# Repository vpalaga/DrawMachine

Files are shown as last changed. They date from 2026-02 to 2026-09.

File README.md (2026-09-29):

# Draw Machine by VPalaga 

The idea is to make a plotter.

 The FCODE is my own simplification of .gcode protocol. I maight implememnt the .gcode later for the sake of my own sanity, but for now I am working with my own fuck creation - FCODE.

**The Goal: 100% working reliable x, y potter to do my homework.** 

>Partially based on Scrabble bot.
---

## .FCODE (quite old examples, they are not accurate at all <3)
>**FCODE Generation example in `FCODEgenerator/useExample.py`**  

``` python
from FCODEgenerator.main import FGenerator

# create a generatin object
gen = FGenerator("train_v1.dxf", acc=.1, vis_scale=10, text=False)

# generate the FCODE from the provided dxf file
gen.generate_instructions()
 # the save format / location can be configured under gen.py method: save()
gen.save()
```

Payload from Pi to Pico examples (FCODE):
```
CALIBRATE
MOVE 45.478 3.671
PENUP
MOVE 67.092 89.082
PENDOWN 
```
| Function | Arguments | Description |
| --- | --- | --- |
| MOVE | 2 | move the head to the x, y position| 
| WAIT | 1 |wait *x* seconds |
| CALIBRATE | 0 | calibrate the head (using the swiches at 0, 0) |
| *PENUP* | 0 | set the pen positon to be up |
| *PENDOWN* | 0 | set the pen position to be down| 

> Current functions: (can be found under `FCODEgenerator.segmentFunctions.Instruction.instructions_parameters_len.keys()`

---
## Raspberry Pi
*Python on Raspberry Pi 4B*   
+ file reading
+ run `MotorControl`
+ send float x, y coordinates to Raspberry Pico 2W
+ control servo on the head (*depending on the current use*) or head in general (PCA PCB)
+ > maybe even web server host for FCODE upload or remote stearing 

> To implement multifunctions, the Inscructions need to have be adjusted to the new argument length 
---
## Raspberry Pico  
Microcontroller running the main `c` loop, basicaly the PICO is just a dual simultanious stepper driver: 
+ recive functions
+ respond with error/confirmantion messages (CDC)
+ drive the end swiches (draw current when closed)
+ Send logic to x, y TMC 2209 Drivers

I am using **Raspberry Pi Pico VS Code extension** to write, compile and upload the code to my Pico.

---
### The idea for the c++ code running on the pico:
USB CDC Virtual Serial data exchange, to send `MOVE` coordinates to the pico.

> CDC Example
``` cpp
// Pico: client
while (true) {
        if (stdio_usb_connected(w)) {
            // read a char if available
            int c = getchar_timeout_us(0);

            if (c >= 0) {
                printf("Got char: %c\n", (char)c);
            }
        }
        sleep_ms(10);
    }
```
> install Python lib `pyserial`
``` python
import serial
import time

# replace with your Pico’s serial port name;
# on Linux it might be "/dev/ttyACM0" or similar
# on Windows something like "COM3"
SERIAL_PORT = "COM14"
BAUDRATE = 115200

# open the serial connection
ser = serial.Serial(SERIAL_PORT, BAUDRATE, timeout=1)

time.sleep(2)    # short delay to let the port settle
ser.write(b"hello world!") # make shure you send the tring in byte type
    
# send a line to the Pico
try:
    while True:

        line_raw = ser.readline()
        line = line_raw.decode().strip()
        if line != "Got char:" and line != "":
            print(line)
        time.sleep(.01)
finally:
    ser.close()
    exit()
```
### Stepping

Stepps moves are computed by Bresenham move function

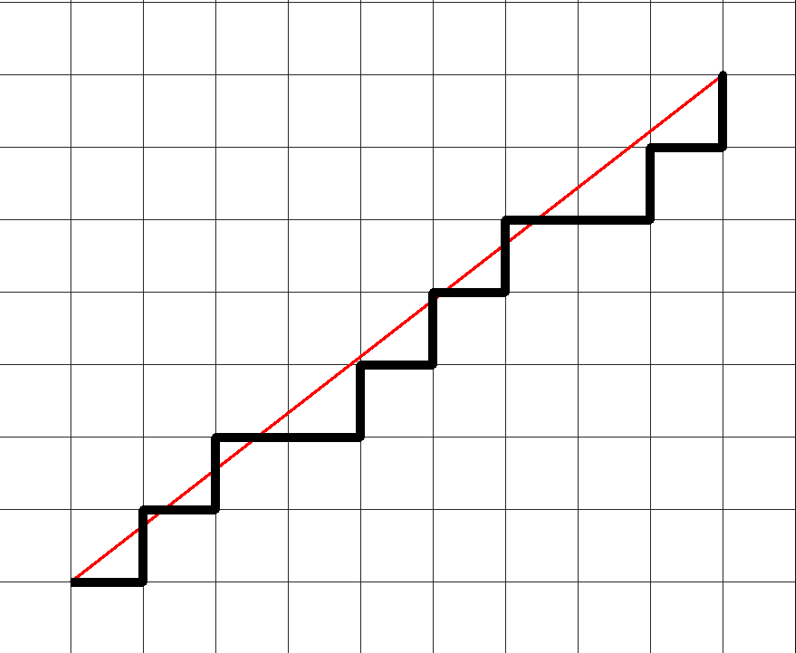
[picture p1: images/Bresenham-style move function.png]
./images/Bresenham-style move function.png


```cpp
class StepperDriver{
public:
    Stepper xStepperMotor;
    Stepper yStepperMotor;

    StepperDriver()
        : xStepperMotor(X_STP_STEPPER_PIN, X_DIR_STEPPER_PIN, 100),
          yStepperMotor(Y_STP_STEPPER_PIN, Y_DIR_STEPPER_PIN, 100) {
    }
    void bresenham(Stepper leadStepper, Stepper followStepper, int lead, int follow, bool leadDir, bool followDir){
        // how many steps of follow pro one step of lead
        float bresenhamStep = (float)follow / lead; // needs to be <0 

        int followPos   = 0;
        int followCycle;
        int diffFollowCycle;

        for (int cycle = 1; cycle<lead+1; cycle++){ // cycle need to start at 1
            
            // calculate how many steps at current cycle position 
            followCycle = round(cycle*bresenhamStep);
            
            // check how many are needed for this cycle
            diffFollowCycle = followCycle - followPos;

            // update the followPos to current follow position
            followPos += diffFollowCycle;

            //move the steppers accordingly
            // step: bool: dir, int steps, microseconds_sleep
            leadStepper.step(leadDir,1,100);
            followStepper.step(followDir,diffFollowCycle,100); // move the follow if needed
        }
    }

    void move(int x, int y){

        bool x_dir = (x<0) ? false : true; // change if the direction is wrong
        bool y_dir = (y<0) ? false : true;

        // set both to positive
        x = abs(x); y = abs(y);

        if (x >= y){ // x = lead
            bresenham(xStepperMotor, yStepperMotor, x, y, x_dir, y_dir);    
        } else { // y = lead
            bresenham(yStepperMotor, xStepperMotor, y, x, y_dir, x_dir);
        }
    }

};

```

---

# Construction
fuck you, find your own parts. I dont care about the nobody reading this to spend my time on this :D
# Code Documentation

Good luck figuring it out on your own. I have no idea either.

## Libraries used:
I have no clue. 
Just go check it lol.

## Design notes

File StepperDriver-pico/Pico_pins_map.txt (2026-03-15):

                              _______
                        ______|     |______
                    GP0 | 1             40|VBUS
                    GP1 | 2  GP25|LED   39|VSYS
                    GND | 3             38| GND      
Swich control X+    GP2 | 4             37|3v3e     
Swich control Y+    GP3 | 5             36|3V3O     3V3 Source
Swich control X-    GP4 | 6             35|
Swich control Y-    GP5 | 7             34|GP28     LED instruction
                    GND | 8             33| GND     Swich DRAIN
Swich B1            GP6 | 9             32|GP27     Swich X pull
Swich B2            GP7 |10             31|GP26     Swich Y pull
PCA9685 I2C_SDA     GP8 |11             30|RUN
PCA9685 I2C_SCL     GP9 |12             29|GP22
PCA9685 GND         GND |13             28| GND     TMC enable
                    GP10|14             27|GP21     TMC Y step
                    GP11|15             26|GP20     TMC Y dir
                    GP12|16             25|GP19     TMC X step
                    GP13|17             24|GP18     TMC X dir
                    GND |18             23| GND     TMC GND
HW069 display CLK   GP14|19             22|GP17     LED consolemode (blue)
HW069 display DIO   GP15|20             21|GP16     LED 2 (no use now)

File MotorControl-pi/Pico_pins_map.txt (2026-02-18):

                              _______
                        ______|     |______
                    GP0 | 1             40|VBUS
                    GP1 | 2             39|VSYS
                    GND | 3             38| GND      
                    GP2 | 4             37|3v3e     
                    GP3 | 5             36|3V3O     3V3 Source
                    GP4 | 6             35|
                    GP5 | 7             34|GP28
                    GND | 8             33| GND     Swich DRAIN
                    GP6 | 9             32|GP27     Swich Y pull
                    GP7 |10             31|GP26     Swich X pull
PCA9685 I2C_SDA     GP8 |11             30|RUN
PCA9685 I2C_SCL     GP9 |12             29|GP22
PCA9685 GND         GND |13             28| GND     TMC enable
Swich control X+    GP10|14             27|GP21     TMC X step
Swich control X-    GP11|15             26|GP20     TMC X dir
Swich control Y+    GP12|16             25|GP19     TMC Y step
Swich control Y-    GP13|17             24|GP18     TMC Y dir
Swich, HW069 GND    GND |18             23| GND     TMC GND
HW069 display CLK   GP14|19             22|GP17     LED instruction
HW069 display DIO   GP15|20             21|GP16     LED 2 (no use now)

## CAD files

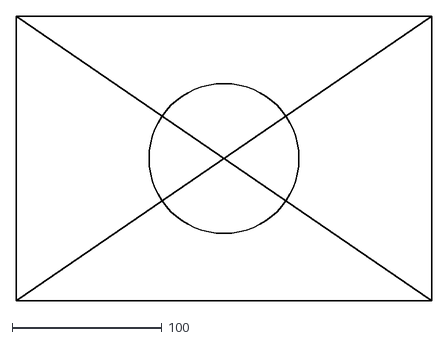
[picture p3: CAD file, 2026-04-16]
FCODEgenerator/dxfexamples/better_circle.dxf
277.0 x 190.0

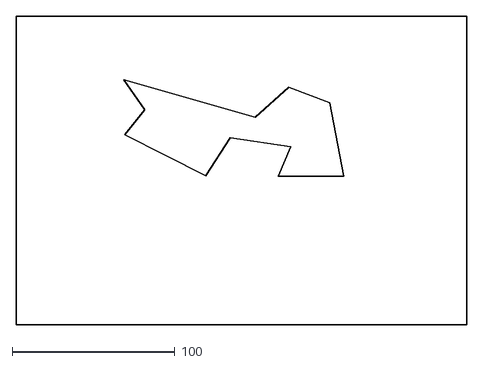
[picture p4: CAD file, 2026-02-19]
FCODEgenerator/simpleShape.dxf
277.0 x 190.0

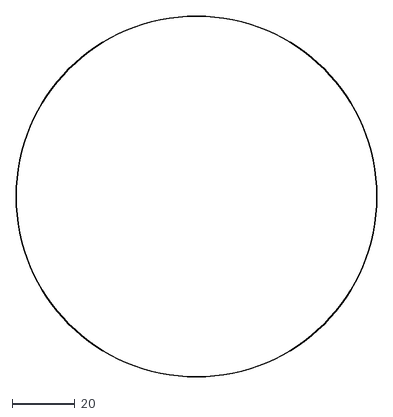
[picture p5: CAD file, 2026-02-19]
FCODEgenerator/dxfexamples/circle.dxf
114.5 x 114.5

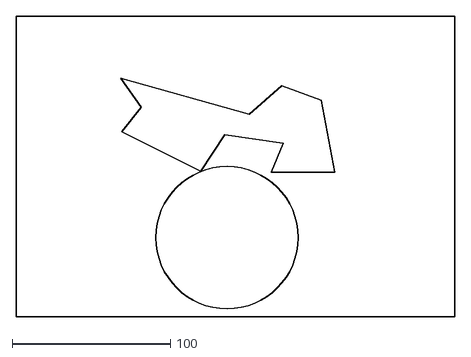
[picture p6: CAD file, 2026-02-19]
FCODEgenerator/dxfexamples/simpleShape(1).dxf
277.0 x 190.0

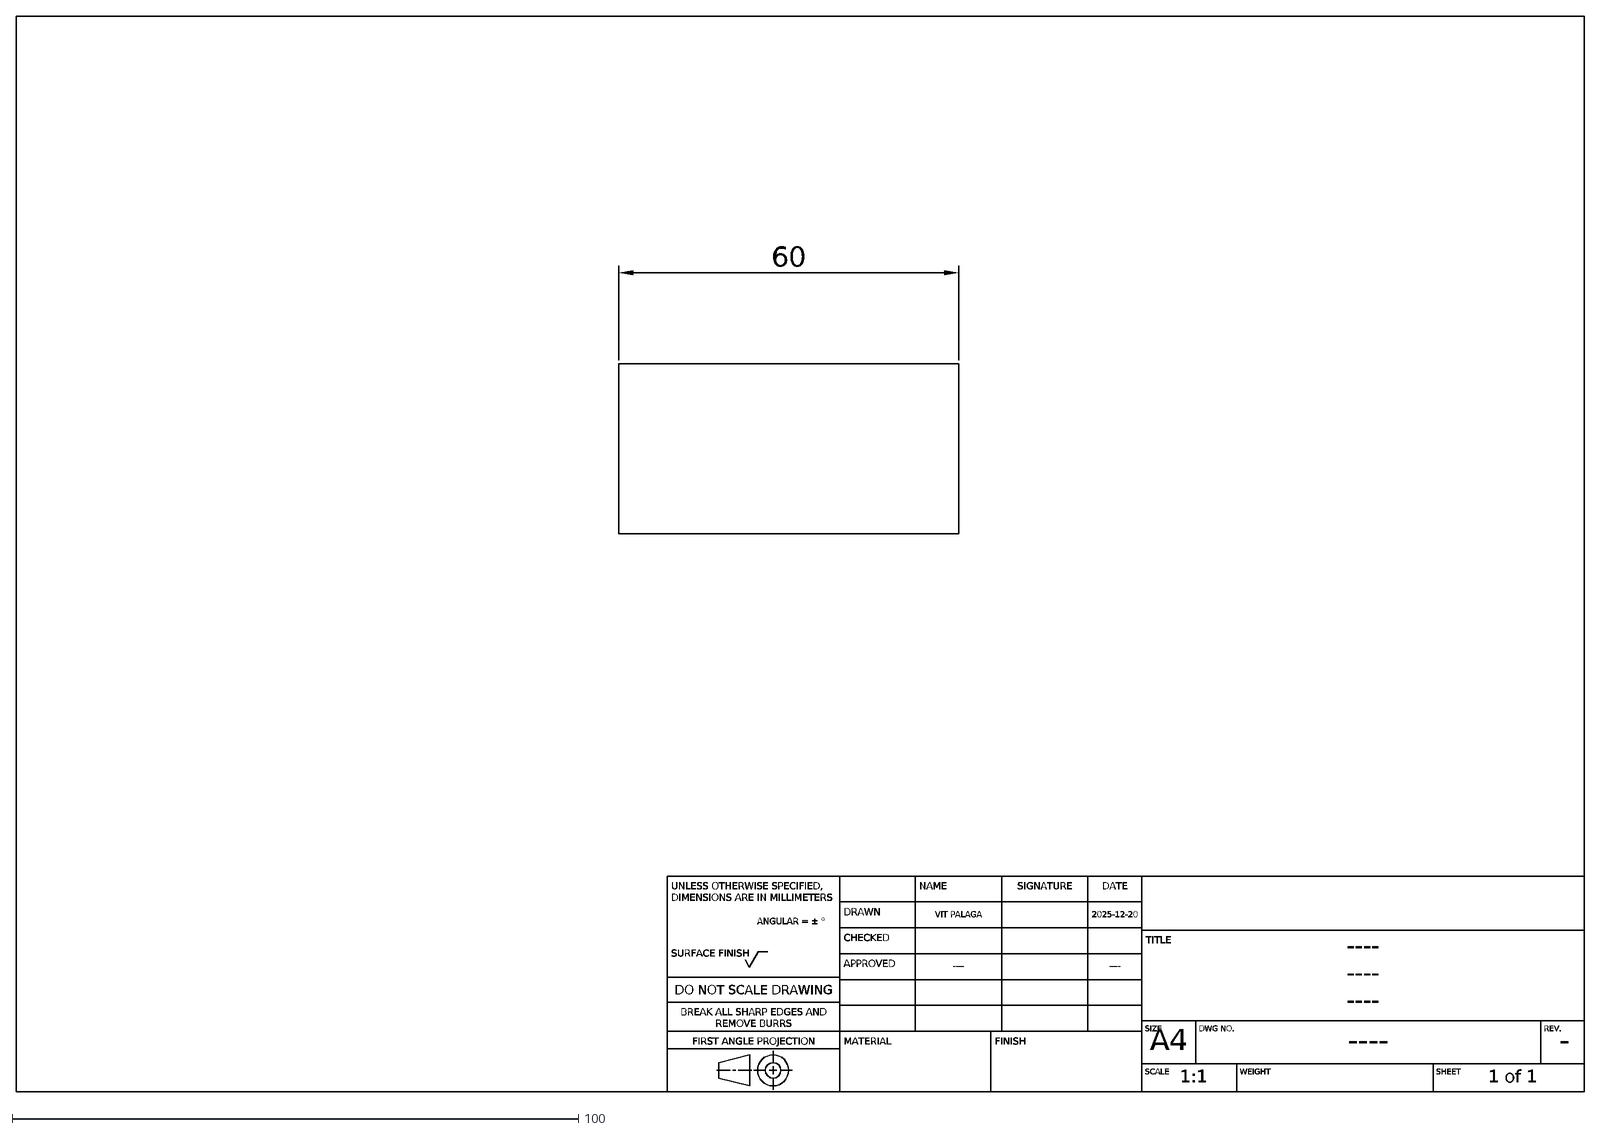
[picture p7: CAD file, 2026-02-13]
FCODEgenerator/dxfexamples/Drawing 2.dxf
UNLESS OTHERWISE SPECIFIED, DIMENSIONS ARE IN MILLIMETERS
ANGULAR = ± °
SURFACE FINISH
DO NOT SCALE DRAWING
BREAK ALL SHARP EDGES AND REMOVE BURRS
FIRST ANGLE PROJECTION
SIGNATURE
NAME
DATE
DRAWN
VIT PALAGA
2025-12-20
CHECKED
APPROVED
----
MATERIAL
FINISH
TITLE
SIZE
A4
DWG NO.
REV.
-
SCALE
1:1
WEIGHT
SHEET
1 of 1
60

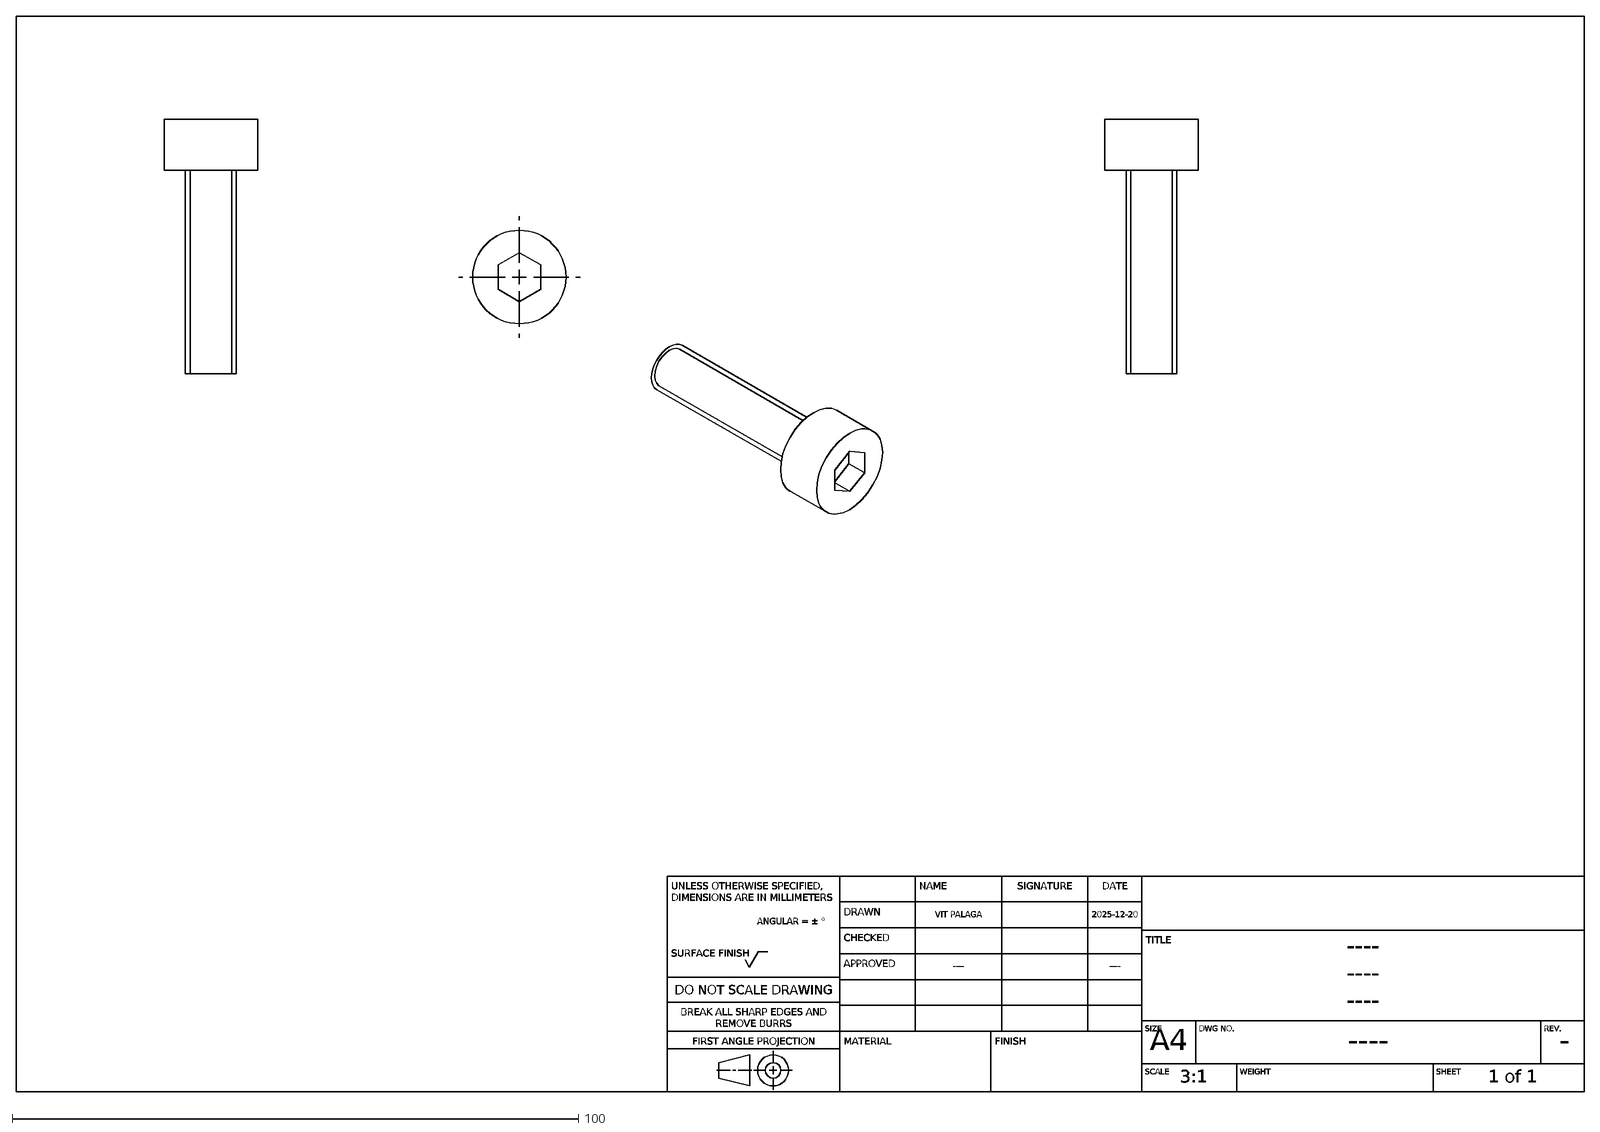
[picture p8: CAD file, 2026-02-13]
FCODEgenerator/dxfexamples/Drawing 1.dxf
UNLESS OTHERWISE SPECIFIED, DIMENSIONS ARE IN MILLIMETERS
ANGULAR = ± °
SURFACE FINISH
DO NOT SCALE DRAWING
BREAK ALL SHARP EDGES AND REMOVE BURRS
FIRST ANGLE PROJECTION
SIGNATURE
NAME
DATE
DRAWN
VIT PALAGA
2025-12-20
CHECKED
APPROVED
----
MATERIAL
FINISH
TITLE
SIZE
A4
DWG NO.
REV.
-
SCALE
3:1
WEIGHT
SHEET
1 of 1

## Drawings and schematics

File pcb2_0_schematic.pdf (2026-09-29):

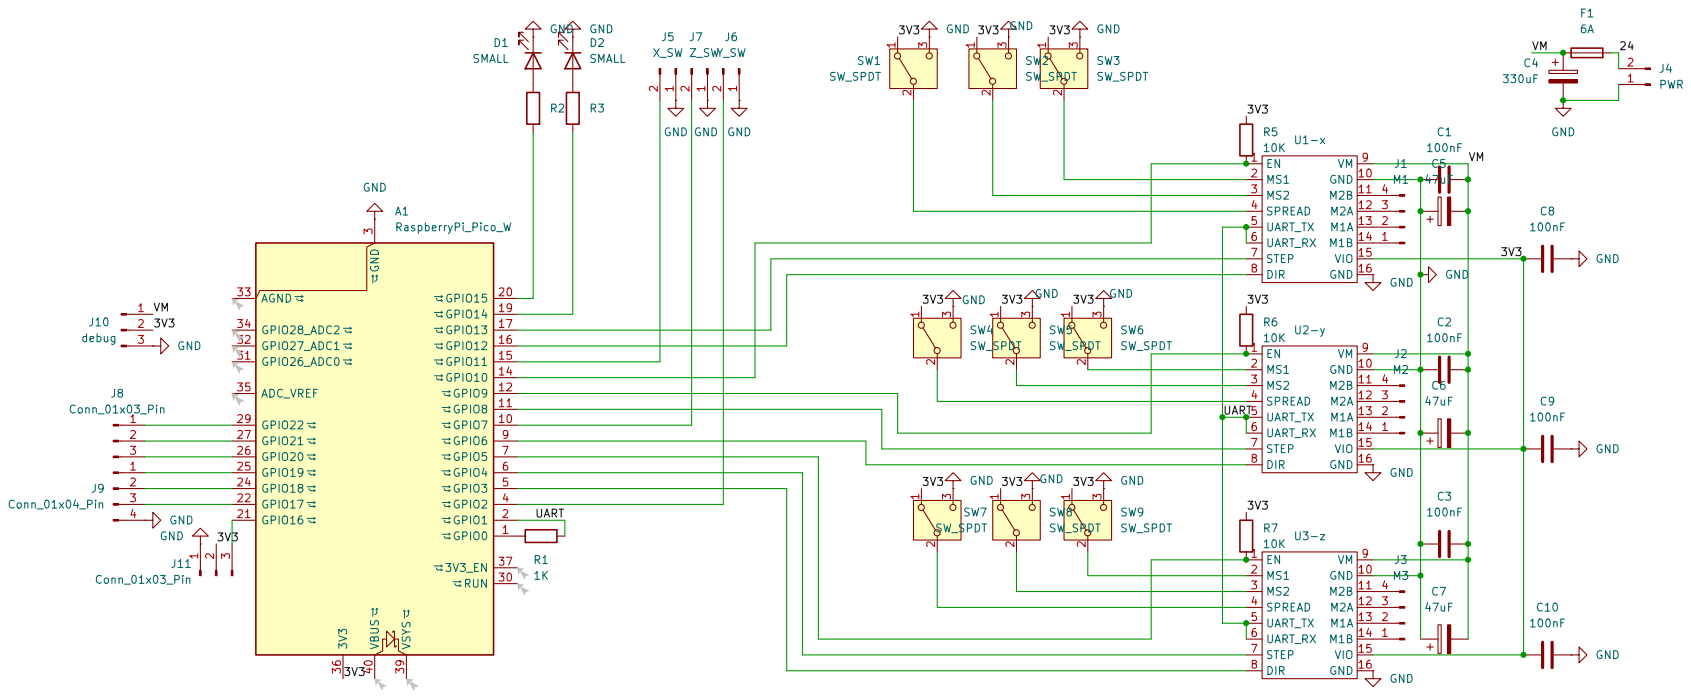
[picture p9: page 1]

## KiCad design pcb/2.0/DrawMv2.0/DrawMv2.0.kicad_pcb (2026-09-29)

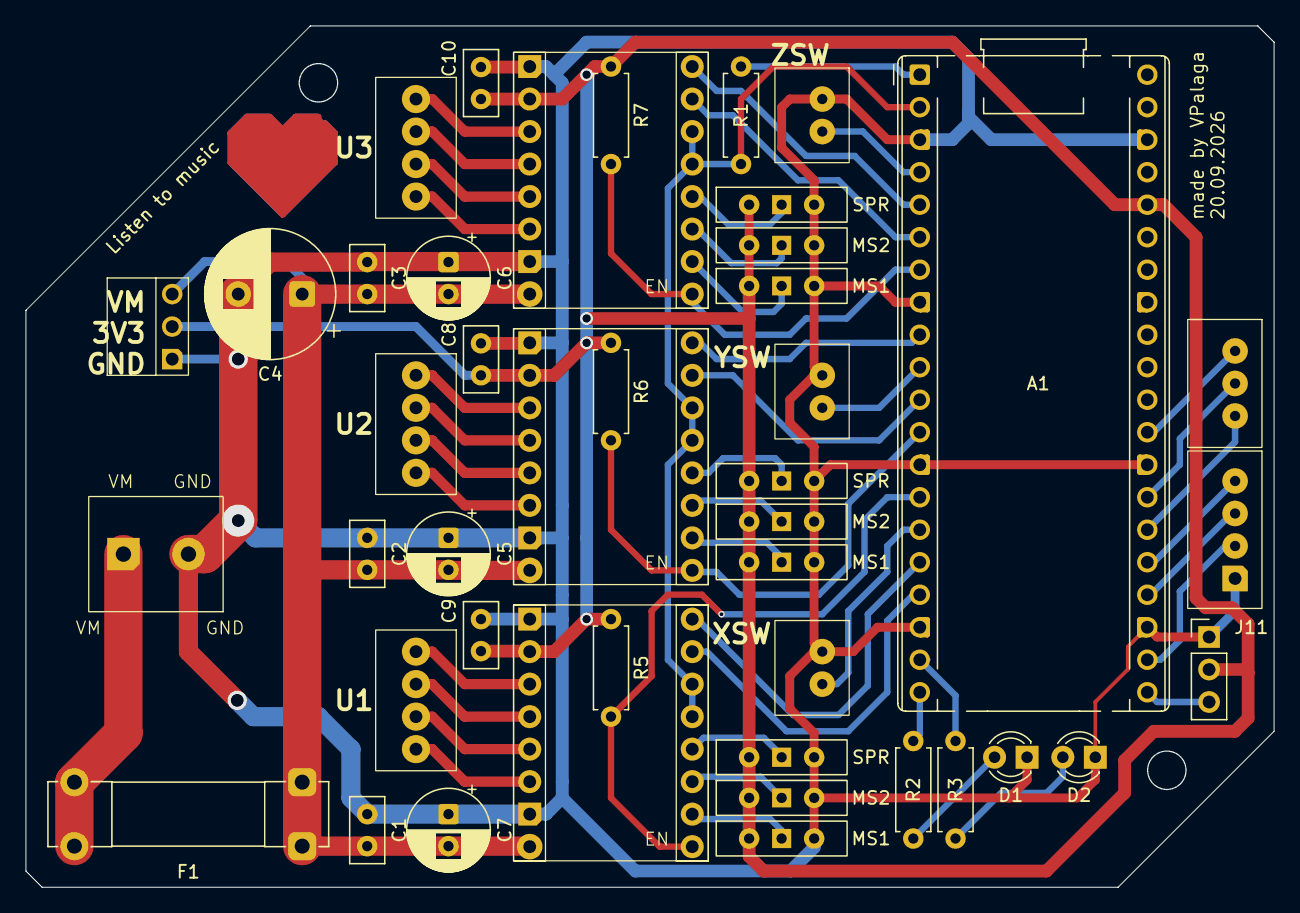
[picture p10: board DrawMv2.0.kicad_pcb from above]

Board: 2 copper layers, 97.5 x 67.3 mm, 43 parts (0 on the bottom side), 50 nets.

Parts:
A1: RaspberryPi_Pico_W; RaspberryPi_Pico_Common_THT
C1, C2, C3, C8, C9, C10: 100nF; C_Disc_D5.0mm_W2.5mm_P2.50mm
C4: 330uF; CP_Radial_D10.0mm_P5.00mm
C5, C6, C7: 47uF; CP_Radial_D6.3mm_P2.50mm
D1, D2: SMALL; LED_D3.0mm
F1: 6A; Fuseholder_Clip-5x20mm_Bel_FC-203-22_Lateral_P17.80x5.00mm_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
J1: M1; 4pinTerminal
J2: M2; 4pinTerminal
J3: M3; 4pinTerminal
J4: PWR; Untitled
J5: X_SW; XH2pin
J6: Y_SW; XH2pin
J7: Z_SW; XH2pin
J8: Conn_01x03_Pin; XH3pin
J9: Conn_01x04_Pin; XH4pin
J10: debug
J11: Conn_01x03_Pin; PinHeader_1x03_P2.54mm_Vertical
MS1, MS1#2, MS1#3, MS2, MS2#2, MS2#3: SW_SPDT; SW_Slide-03_Wuerth-WS-SLTV_10x2.5x6.4_P2.54mm_ok
R1: 1K; R_Axial_DIN0207_L6.3mm_D2.5mm_P7.62mm_Horizontal
R2, R3: R_Axial_DIN0207_L6.3mm_D2.5mm_P7.62mm_Horizontal
R5, R6, R7: 10K; R_Axial_DIN0207_L6.3mm_D2.5mm_P7.62mm_Horizontal
SPR: SW_SPDT; SW_Slide-03_Wuerth-WS-SLTV_10x2.5x6.4_P2.54mm_ok
SPR#2, SPR#3: SW_SPDT; SW_Slide-03_Wuerth-WS-SLTV_10x2.5x6.4_P2.54mm_ok
U1, U2, U3: TMC2209

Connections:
/3V3: A1.36 (3V3), C8.1, C9.1, C10.1, J10.2, J11.2, MS1.1 (A), MS1#2.1 (A), MS1#3.1 (A), MS2.1 (A), MS2#2.1 (A), MS2#3.1 (A), R5.1, R6.1, R7.1, SPR.1 (A), SPR#2.1 (A), SPR#3.1 (A), U1.15 (VIO), U2.15 (VIO), U3.15 (VIO)
/24: F1.2, J4.2
/UART: A1.2 (GPIO1), R1.1, U1.5 (UART_TX), U1.6 (UART_RX), U2.5 (UART_TX), U2.6 (UART_RX), U3.5 (UART_TX), U3.6 (UART_RX)
/VM: C1.2, C2.2, C3.2, C4.1, C5.2, C6.2, C7.2, F1.1, J10.1, U1.9 (VM), U2.9 (VM), U3.9 (VM)
GND: A1.3 (GND), A1.8 (GND), A1.13 (GND), A1.18 (GND), A1.23 (GND), A1.28 (GND), A1.38 (GND), C1.1, C2.1, C3.1, C4.2, C5.1, C6.1, C7.1, C8.2, C9.2, C10.2, D1.1 (K), D2.1 (K), J4.1, J5.1, J6.1, J7.1, J9.4, J10.3, J11.1, MS1.3 (C), MS1#2.3 (C), MS1#3.3 (C), MS2.3 (C), MS2#2.3 (C), MS2#3.3 (C), SPR.3 (C), SPR#2.3 (C), SPR#3.3 (C), U1.10 (GND), U1.16 (GND), U2.10 (GND), U2.16 (GND), U3.10 (GND), U3.16 (GND)
unnamed: A1.1 (GPIO0), R1.2
unnamed: A1.4 (GPIO2), J6.2
unnamed: A1.5 (GPIO3), U3.8 (DIR)
unnamed: A1.6 (GPIO4), U3.7 (STEP)
unnamed: A1.7 (GPIO5), R7.2, U3.1 (EN)
unnamed: A1.9 (GPIO6), U2.8 (DIR)
unnamed: A1.10 (GPIO7), J7.2
unnamed: A1.11 (GPIO8), U2.7 (STEP)
unnamed: A1.12 (GPIO9), R6.2, U2.1 (EN)
unnamed: A1.14 (GPIO10), R5.2, U1.1 (EN)
unnamed: A1.15 (GPIO11), J5.2
unnamed: A1.16 (GPIO12), U1.8 (DIR)
unnamed: A1.17 (GPIO13), U1.7 (STEP)
unnamed: A1.19 (GPIO14), R3.1
unnamed: A1.20 (GPIO15), R2.1
unnamed: A1.21 (GPIO16), J11.3
unnamed: A1.22 (GPIO17), J9.3
unnamed: A1.24 (GPIO18), J9.2
unnamed: A1.25 (GPIO19), J9.1
unnamed: A1.26 (GPIO20), J8.3
unnamed: A1.27 (GPIO21), J8.2
unnamed: A1.29 (GPIO22), J8.1
unnamed: D1.2 (A), R2.2
unnamed: D2.2 (A), R3.2
unnamed: J1.1, U1.14 (M1B)
unnamed: J1.2, U1.13 (M1A)
unnamed: J1.3, U1.12 (M2A)
unnamed: J1.4, U1.11 (M2B)
unnamed: J2.1, U2.14 (M1B)
unnamed: J2.2, U2.13 (M1A)
unnamed: J2.3, U2.12 (M2A)
unnamed: J2.4, U2.11 (M2B)
unnamed: J3.1, U3.14 (M1B)
unnamed: J3.2, U3.13 (M1A)
unnamed: J3.3, U3.12 (M2A)
unnamed: J3.4, U3.11 (M2B)
unnamed: SPR#3.2 (B), U1.4 (SPREAD)
unnamed: MS2#2.2 (B), U1.3 (MS2)
unnamed: MS1#2.2 (B), U1.2 (MS1)
unnamed: SPR.2 (B), U2.4 (SPREAD)
unnamed: MS2#3.2 (B), U2.3 (MS2)
unnamed: MS1#3.2 (B), U2.2 (MS1)
unnamed: SPR#2.2 (B), U3.4 (SPREAD)
unnamed: MS2.2 (B), U3.3 (MS2)
unnamed: MS1.2 (B), U3.2 (MS1)

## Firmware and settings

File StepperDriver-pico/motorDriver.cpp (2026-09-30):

#include <stdio.h>
#include <string>
#include <vector>
#include <sstream>
#include <map>
#include <math.h>
#include <cmath>
#include <cstdint>

#include "pico/stdlib.h"
#include "hardware/i2c.h"
#include "hardware/timer.h"
#include "hardware/clocks.h"
#include "hardware/i2c.h"

#include "algorithm"

#include "drivers/Led.h"
#include "drivers/StepperDriver.h" 
#include "drivers/SwitchButton.h"
#include "drivers/Stepper.h"

using namespace std;

int64_t alarm_callback(alarm_id_t id, void *user_data) {
    // Put your timeout handler code in here
    return 0;
}

const int BUF_MAX_LEN = 128;

uint8_t consoleEnabled = 2; // 2 for unassigned 1 true 0 false

// instruction type vs arguments
const map<string, int> INSTRUCTION_SIZES = {
    {"MOV", 2},// xsteps ysteps
    {"CLB", 0},// 
    {"WAT", 1},// seconds
    {"PUP", 0}, // 
    {"PDN", 0}, // 
    {"SCM", 1} // mode (0,1,2)
};
//=============================================================

// manual control swiches
SwitchButton mSwich_XP(22);
SwitchButton mSwich_XM(21);
SwitchButton mSwich_YP(20);
SwitchButton mSwich_YM(19);
SwitchButton mSwich_B1(18);
SwitchButton mSwich_B2(17);

// end swiches, use with calibrate
SwitchButton xSwich(11);
SwitchButton ySwich(7);
SwitchButton zSwich(2); 

// leds
Led instructionLed(15);
Led ledConsoleMode(14);

// driver: xstp xdir ystp ydir
Stepper::stepper_pins x_stepper_pins = {4, 3, 5};
Stepper::stepper_pins y_stepper_pins = {8, 6, 9};
Stepper::stepper_pins z_stepper_pins = {13, 12, 10};

struct Settings {
    const uint16_t z_stepper_us_sleep = 50; 
    const int pen_up_down_steps = 300; // needs to be tested 
    const int INSTRUCION_TIMEOUT_MS = 3000; 
    const uint16_t x_y_halfcycle_us_sleep = 50;
}settings;


StepperDriver stepper_driver(x_stepper_pins, x_stepper_pins);
Stepper z_stepper(z_stepper_pins);

void z_stepper_calibrate(){
    while (!zSwich.getSwichState()){ // dosnt conduct
        // i dont think a sleep is needed here, since 900 steps = 1mm move, so should be more than enough time to stop
        // move into z+ direction
        z_stepper.move(1, settings.z_stepper_us_sleep); // move one step x back (-)
    }
    stepper_driver.is_pen_down = false;
}

class Instructions{
public:
    static bool wait(float seconds){

        sleep_ms(seconds*1000); // make into mini seconds

        return false;
    }

    static bool move(int x, int y){

        stepper_driver.enable(true);
        stepper_driver.move(x, y);
        
        return false; // move 
    }

    static bool calibrate(){

        while ((!xSwich.getSwichState()) && (!ySwich.getSwichState())){ // dosnt conduct
            // i dont think a sleep is needed here, since 900 steps = 1mm move, so should be more than enough time to stop
            stepper_driver.move(-1, -1); // move one step x back (-)
        }
        while (!xSwich.getSwichState()){ // dosnt conduct
            // i dont think a sleep is needed here, since 900 steps = 1mm move, so should be more than enough time to stop
            stepper_driver.move(-1, 0); // move one step x back (-)
        }
        while (!ySwich.getSwichState()){ // dosnt conduct
            // i dont think a sleep is needed here, since 900 steps = 1mm move, so should be more than enough time to stop
            stepper_driver.move(0, -1); // move one step x back (-)
        }
        // reset stepper pos
        stepper_driver.pos_reset();

        // z calib
        z_stepper_calibrate();

        return false; // calibrate 
    }

    static bool pen_up(){
        // check last known pen pos
        if (!stepper_driver.is_pen_down){return true;}

        // move +z direction
        z_stepper.move(settings.pen_up_down_steps, settings.z_stepper_us_sleep);
        stepper_driver.is_pen_down = false;

        return false;
    }
    
    static bool pen_down(){
        // check last known pen pos
        if (stepper_driver.is_pen_down){return true;}

        // move -z direction
        z_stepper.move(- settings.pen_up_down_steps, settings.z_stepper_us_sleep);
        stepper_driver.is_pen_down = true;

        return false;
    }

    static bool set_instruction_mode(uint8_t mode){
        consoleEnabled = mode;
        return false;
    }
};

pair<string, vector<float>> get_instruction_details(string instruction){
	// return string Instruction type, int* args4

	istringstream iss(instruction);
	vector<string> parts;
	vector<float> arguments;// store
	string part;

	string instruction_type; // first object in parts
	int parameters_size;

	while (iss >> part) {   // splits on whitespace by default
		parts.push_back(part);
	}

	instruction_type = parts[0];
	parameters_size = parts.size() - 1; // ignore the firts part

	for (int i = 1; i<parameters_size+1;i++) { // shift i by +1, so i can acces vector[i] ang skip the first element
		// convert str argumetents to floats
		arguments.push_back(stof(parts[i]));
	}
	/*
	for (const auto&  : words) {

		cout << w << "\n";
	}
	*/
	return {instruction_type, arguments};
}

// stuff for CDC full string recive
char rx_buf[BUF_MAX_LEN];
int rx_pos = 0;
int c;

//=============================================================

// send message to rsb, false=good, true=unusable
void confirm_recive(bool state){
    // false = all good
    // true error
    printf("%d\n", state); // dont forget to end message by '\n'
}

// wait for connection
void waitForCDC(){
    while (!stdio_usb_connected()) {
        sleep_ms(100);
    }
}

void process_received(const string buf, int len) {
    // return false (0): the message is OK 
    // return true  (1): the message is unsable
    // handle complete message (null-terminated)
    

    auto instructionDetails = get_instruction_details(buf);

    string instructionType = instructionDetails.first;
    vector<float> instructionArgunments = instructionDetails.second;
    
    // check instruction usability
    
    // state of recived message
    bool recivedMessageState = false;

    if (INSTRUCTION_SIZES.count(instructionType) == 0){ //check if instruction is valid, if 1=false, 0=true
        recivedMessageState = true;
    }    
    if (INSTRUCTION_SIZES.at(instructionType) != (instructionArgunments.size())){ //check arguments size
        recivedMessageState = true;

    }

    // send out the state of recived message
    confirm_recive(recivedMessageState);
    

    if (recivedMessageState) return; // an error has happened

    // paths to different instructions
    bool instructionFinished = true;
    
    if          (instructionType=="MOV"){
    
        instructionFinished = Instructions::move(instructionArgunments[0], instructionArgunments[1]);
    
    } else if   (instructionType=="CLB"){
        // calibrate
        instructionFinished = Instructions::calibrate();

    } else if   (instructionType=="WAT"){
        // wait x seconds
        instructionFinished = Instructions::wait(instructionArgunments[0]);

    } else if (instructionType=="PUP"){
        // channel, angle
        instructionFinished = Instructions::pen_up();
    } else if (instructionType=="PDN"){
        // channel, angle
        instructionFinished = Instructions::pen_down();  
    
    } else if (instructionType=="SCM"){
        // mode
        instructionFinished = Instructions::set_instruction_mode((uint8_t)instructionArgunments[0]);
    }


    // send out if the instruction was run wihtout problems, false=good, true=unusable 
    confirm_recive(instructionFinished);
}

void manual_instruction(){
    int8_t x_move = 0;
    int8_t y_move = 0;

    if(mSwich_XP.getSwichState()){
        x_move++;
        if(consoleEnabled == 1){
            printf("B1 (xp): pressed");
        }    
    }

    if(mSwich_XM.getSwichState()){
        x_move--;
        if(consoleEnabled == 1){
            printf("B2 (xm): pressed\n");
            printf("x: %d\n", xSwich.getSwichState());
            printf("y: %d\n", ySwich.getSwichState());
            sleep_ms(20);
        }    
    }

    if(mSwich_YP.getSwichState()){
        y_move++;
        if(consoleEnabled == 1){
            printf("B3 (yp): pressed");
        }    
    }

    if(mSwich_YM.getSwichState()){
        y_move--;
        if(consoleEnabled == 1){
            printf("B4 (ym): pressed");
        }    
    }

    if(mSwich_B1.getSwichState()){ // print head position
        if (consoleEnabled == 1){
            stepper_driver.printPosToTermial();
            printf("B5: pressed");
            sleep_ms(700);
        }
    }

    if(mSwich_B2.getSwichState()){
        if(consoleEnabled){
            printf("B6: pressed");
        }    
}

    // move the motors if needed
    if (x_move != 0 || y_move != 0){
        stepper_driver.enable(true);
        stepper_driver.move(x_move, y_move);
        stepper_driver.enable(false);
        
    }

    return;
}

// main functions:

bool CDC_loop(){
    // get full buffer
    while (true) {
        c = getchar_timeout_us(0);
        
        if (c == PICO_ERROR_TIMEOUT){ 
            break; // no more data, or no data to start with
        }
        if (rx_pos < BUF_MAX_LEN - 1) {
            rx_buf[rx_pos++] = (char)c;
        }
        // optional: detect end-of-line to process early, should allways be the case
        if (c == '\n' || c == '\r') {
            break;
        }
    }

    // work with recived string
    if (rx_pos > 0) {
        rx_buf[rx_pos] = '\0';    // null terminate
        
        // convert char* to std::string
        string message(rx_buf);
        process_received(message, rx_pos);

        // reset for next message
        rx_pos = 0;
        return true;
    }
    return false;
}

int time_from_last_inst;

int main()
{
    stdio_init_all();
    // set to thing in settings
    stepper_driver.motor_sleep_us = settings.x_y_halfcycle_us_sleep;

    while (true) { // CDC loop
        
        if (CDC_loop()){time_from_last_inst=0;} else {time_from_last_inst++;}
        
        sleep_ms(1); // bottle neck, ignore for now

        if (time_from_last_inst > settings.INSTRUCION_TIMEOUT_MS){
            // enable manual control
            instructionLed.setState(false);
            stepper_driver.enable(false);

            manual_instruction();

        } 
        
        // reset instruction led after reciving an istructon
        if (time_from_last_inst == 0){instructionLed.setState(true);}
        if (consoleEnabled != ledConsoleMode.state && consoleEnabled != 2)   {ledConsoleMode.setState(consoleEnabled);}
    }   
}

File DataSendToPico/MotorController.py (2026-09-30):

from MotorOverclass import StepperMotor
from CDC_send import Transmitter
from idkfornow import RequestReport, RequestFailCheck
import settings

class MotorOutOfRangeError(Exception):#
    def __init__(self, motor:StepperMotor, difference:float|int):
        self.message = f"{motor.name} out of range: from'{motor.pos_mm}' to '{motor.pos_mm+difference}"
        super().__init__(self.message)

class MotorController:
    """control x and y motors with the move (x, y) function, use calibrating to reset motor positions to 0, 0
       and move servos
    """
    starting_offsets_user_presets = { # in mm from left bottom corner
        "A4": (45, 40) # measure
    }

    def __init__(self, move_format="A4"):

        # CDC send instruction object
        self.transmitter = Transmitter(console=False)

        #stepper motor objects to store the bullshit motor data
        self.x_motor = StepperMotor(name="x_motor", max_pos_mm=297, tmc_mirco_spt=16) # measure
        self.y_motor = StepperMotor(name="y_motor", max_pos_mm=210, tmc_mirco_spt=16) # measure

        # deal with starting offset (x, y)
        if move_format in MotorController.starting_offsets_user_presets.keys():# and type(move_format) == str:
            self.starting_offset = MotorController.starting_offsets_user_presets[str(move_format)] # (offset_x, offset_y)
        #else: # user can input custom (offset_x, offset_y)
        #    self.starting_offset = move_format

        # calib
        self.calibrate()

    def move_to_mm(self, x_target:float, y_target:float)->None:
        """(target - current) (x, y)"""
        
        x_move = x_target - self.x_motor.pos_mm
        y_move = y_target - self.y_motor.pos_mm

        self.mm_move(x=x_move,y=y_move)

    def mm_move(self, x:float, y:float)->None:
        """move by X, Y mm"""

        #check move and add variable position:
        #check x pos
        if self.x_motor.check_pos(x):
            # store to perform subt
            x_motor_move_starting_mmpos = self.x_motor.pos_mm

            self.x_motor.pos_mm += x # update the mm variable in stepper object

            # calculate the steps, based on the position of required mm pos and current mm pos, due to rounding errors
            x_steps = round(self.x_motor.steps_p_mm * (self.x_motor.pos_mm - x_motor_move_starting_mmpos)) # 10mm*1800steps = 18000 steps

        else:
            raise MotorOutOfRangeError(self.x_motor, x)
        # check y pos

        if self.y_motor.check_pos(y):
            # store to perform subt
            y_motor_move_starting_mmpos = self.y_motor.pos_mm

            self.y_motor.pos_mm += y # update the mm variable in stepper object

            # calculate the steps, based on the position of required mm pos and current mm pos, due to rounding errors
            y_steps = round(self.y_motor.steps_p_mm * (self.y_motor.pos_mm - y_motor_move_starting_mmpos)) # 10mm*1800steps = 18000 steps

        else:
            raise MotorOutOfRangeError(self.y_motor, y)

        # x or y may be undefined, but if they are, Motor error will be raised
        
        self.step_move(x=x_steps, y=y_steps)

    @RequestReport
    def step_move(self, x:int, y:int)->None:
        if not settings.TEST_MODE:
            receive_state = self.transmitter.send_and_receive("MOV " + str(x) + " " + str(y) + "\n")
            finish_state = self.transmitter.send_and_receive(None) # wait for finish
            RequestFailCheck(receive_state, finish_state)

    @RequestReport
    def calibrate(self)->None:
        # send calibrate instruction

        if not settings.TEST_MODE:
            receive_state = self.transmitter.send_and_receive("CLB\n")
            finish_state = self.transmitter.send_and_receive(None) # wait for finish
            RequestFailCheck(receive_state, finish_state)

            # move to starting offset
            self.move_to_mm(*MotorController.starting_offsets_user_presets["A4"])

        # reset the motors
        self.x_motor.reset()
        self.y_motor.reset()

        #reset the servo as well?

    @RequestReport
    def penUp(self):
        if not settings.TEST_MODE:
            receive_state = self.transmitter.send_and_receive("PUP\n")
            finish_state = self.transmitter.send_and_receive(None) # wait for finish
            RequestFailCheck(receive_state, finish_state)

    @RequestReport
    def penDown(self):
        if not settings.TEST_MODE:
            receive_state = self.transmitter.send_and_receive("PDN\n")
            finish_state = self.transmitter.send_and_receive(None) # wait for finish
            RequestFailCheck(receive_state, finish_state)

    @RequestReport
    def wait(self, secs):
        receive_state = self.transmitter.send_and_receive("WAT " + secs + "\n")
        finish_state = self.transmitter.send_and_receive(None) # wait for finish
        RequestFailCheck(receive_state, finish_state)

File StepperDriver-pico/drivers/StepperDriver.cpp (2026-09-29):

#include "StepperDriver.h"
#include "pico/stdlib.h"
#include <stdio.h>
#include <cmath>

StepperDriver::StepperDriver(Stepper::stepper_pins pins_x, Stepper::stepper_pins pins_y)
        : xStepperMotor(pins_x),
          yStepperMotor(pins_y) {
    const int STEPS_P_ROT = 1000;
    const int ROD_PITCH_mm = 2;

    const int USE_SPROFILE_FROM_STEPS = 200;
    const int STEPS_P_1MM = STEPS_P_ROT / ROD_PITCH_mm;
    const double MM_p_STEP = (double)1 / STEPS_P_1MM;
};
void StepperDriver::move(int x, int y){
    if(x == 0 && y == 0){return;}
    // update stepper pos
    x_pos += x; 
    y_pos += y;

    bool x_dir = (x<0) ? true : false; // change if the direction is wrong
    bool y_dir = (y<0) ? true : false;

    // set both to positive
    x = abs(x); y = abs(y);

    if (x >= y){ // x = lead
        bresenham(xStepperMotor, yStepperMotor, x, y, x_dir, y_dir);    
    } else {
        bresenham(yStepperMotor, xStepperMotor, y, x, y_dir, x_dir);
    }
    return;
};

void StepperDriver::bresenham(Stepper leadStepper, Stepper followStepper, int lead, int follow, bool leadDir, bool followDir){
    // how many steps of follow pro one step of lead
    float bresenhamStep = (float)follow / lead; // needs to be <0 

    int followPos   = 0;
    int followCycle;
    int diffFollowCycle;
    
    for (int cycle = 1; cycle<lead+1; cycle++){ // cycle need to start at 1
        
        // calculate how many steps at current cycle position 
        followCycle = round(cycle*bresenhamStep);
        
        // check how many are needed for this cycle
        diffFollowCycle = followCycle - followPos;

        // update the followPos to current follow position
        followPos += diffFollowCycle;
        
        //move the steppers accordingly
        if (diffFollowCycle != 0){
            leadStepper.step_firstHalf(leadDir);
            followStepper.step_firstHalf(followDir); // move the follow if needed
            sleep_us(motor_sleep_us);
            leadStepper.step_secondHalf();
            followStepper.step_secondHalf();
            sleep_us(motor_sleep_us);

        } else {
            leadStepper.step_firstHalf(leadDir);
            sleep_us(motor_sleep_us);
            leadStepper.step_secondHalf();
            sleep_us(motor_sleep_us);
        }
    }
    return;
}

void StepperDriver::enable(bool setState){
    xStepperMotor.enable(setState);
    yStepperMotor.enable(setState);
}

void StepperDriver::pos_reset(){
    x_pos = y_pos = 0;
};

void StepperDriver::printPosToTermial(){
    printf("head pos: X: %.4fmm, Y: %.4fmm \n", (x_pos * MM_p_STEP), (y_pos * MM_p_STEP)); // round up to 4 digets -> r(10**4)/10**4
};

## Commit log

2025-12-27 added main logic for MotorControll
2026-02-10 Enhance README with FCODE and construction details
    Updated README with detailed sections on FCODE, Raspberry Pi, and construction specifications.
2026-02-12 Update README with robot and control system details
    Clarified robot description and added details about Z-axis and Raspberry Pico functionality.
2026-02-12 updates on the swich driver
2026-02-12 rename and fix calibrate call
    [MotorController.py]
2026-02-12 refractor the FCODE generator data structure
    [Drawing 1.dxf, Drawing 2.dxf]
2026-02-12 remind my self to refractor schiwch driver to c
2026-02-13 Revise README with updated FCODE and construction info
    Updated README.md to reflect changes in FCODE examples, Raspberry Pi setup, and construction details.
2026-02-13 fixed the exaple useage
    [Drawing 1.dxf, Drawing 2.dxf]
2026-02-13 Revise README with examples and instructions
    Updated examples and clarified instructions for Raspberry Pi and Pico integration.
2026-02-13 add the raspberry pi cpp start module, with usb enable conifg
2026-02-14 add LED class
    when swich pressed, the leds comply
2026-02-14 add Stepper Class (working)
2026-02-15 string CDC socket
2026-02-15 change Instruction Types to 3 upper letter only
    "MOVE": -> "MOV"
    "PENUP": ->"PUP"
    "PENDOWN"->"PDN"
    "WAIT" ->"WAT"
    "CALIBRATE" ->"CLB"
2026-02-16 fix arguments size cherck bug, (2h - fuck this shit)
    [CDC_send.py, CDC_test.py, motorDriver.cpp]
2026-02-17 create stepper driver (cpp and py) python tested
2026-02-17 fix Bresenham-style move function bug
    [motorDriver.cpp]
2026-02-17 Document StepperDriver class and Bresenham function
    Added documentation for the StepperDriver class and its Bresenham move function.
2026-02-17 code calibrate and test, add instruction led
2026-02-17 add display driver
2026-02-18 add PCA9685 driver (untested)
2026-02-18 review python motor driver and fix bugs and connect it to cdc send_recive func
    [CDC_send.py, MotorController.py, MotorOverclass.py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]
2026-02-18 add servo instructions to pico
2026-02-19 test and implement controller, get first FCODE file running on one stepper (second not avalible)
    [Drawing 1.dxf, Drawing 2.dxf, simpleShape.dxf]
2026-02-19 add penis init screen
    [circle.dxf, simpleShape(1).dxf]
2026-02-28 change servo protocol and add manual instructions
2026-03-01 add give pos button
2026-03-01 fix manual movement pos output
    [CDC_test.py, motorDriver.cpp]
2026-03-01 speed profile bug fixes
    [CDC_send.py, motorDriver.cpp]
2026-04-12 fix typos and accord gpio pinout on pico
    [CDC_send.py, CDC_test.py, Controller.py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]
2026-04-16 added separat tmc setting and test buttons and accord them to real
2026-04-16 - change speed profile - find FCODE generator bug: circle x center is moved by + cca 1cm has been a problem before, bruteforce it?
    [better_circle.dxf]
2026-04-17 - add pcb files - vibe remake dxf reader (gpt) -> fixed the offset bug
    [test-B_Cu.gbr, test-B_Mask.gbr, test-B_Paste.gbr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]
2026-06-24 add drivers
2026-06-24 integrate the drivers
2026-09-29 add the third stepper for z and update for the pcb 2.0
2026-09-29 add pcb2.0
    [DrawMv2.0.kicad_pcb, DrawMv2.0.kicad_sch]
2026-09-30 - add pcb files - vibe remake dxf reader (gpt) -> fixed the offset bug just bunch of updates overall add also the reporter to all motor stuff
    [CDC_send.py, CDC_test.py, Controller.py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]
2026-09-30 update the request shortcuts for the 3rd stepper motor
    [MotorController.py]
2026-09-30 upadte git ignore to exlude some pcb files (.history)
2026-10-01 update the fcode generator with claude:
    1. Fixed and type-hinted the DXF reader (dxfReader.py)
    Fixed the MTEXT rotation sign bug, the line spacing and the anchor handling.
    Stopped the code from modifying the drawing while reading it. Text lines are now virtual entities, and dimensions and block inserts are expanded in memory.
    Made text glyphs flatten per sub-path, so holes no longer get joined by stray lines.
    LWPOLYLINE now handles bulges and the closed flag, and ARC handles extrusion and has a consistent resolution.
    Fixed partial ellipse segment counts, and generate_hatch_lines now clips to the polygon and no longer loops forever on bad spacing.
    Added support for POLYLINE, SPLINE, ATTRIB a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
2026-10-15 fix python fcode gen with cluade, fix the z head clibration , reconsider how xy steppers are enabled
2026-10-17 update cpp pico files and add head calibration (HCB)
2026-10-17 update send pico files
2026-10-18 add homing
2026-10-18 fix argument print
2026-10-19 add v2 pcb image
2026-10-19 separate the head driver
2026-10-19 implement SMS (set motor speed a, b)
2026-10-19 try implementing the pen up with switch
2026-10-20 implement partial calibration on pen up, and set up steps command
2026-10-20 move calibration into steper driver
2026-10-20 move max steps to coresponding driver
2026-10-20 fix look for pico issue
